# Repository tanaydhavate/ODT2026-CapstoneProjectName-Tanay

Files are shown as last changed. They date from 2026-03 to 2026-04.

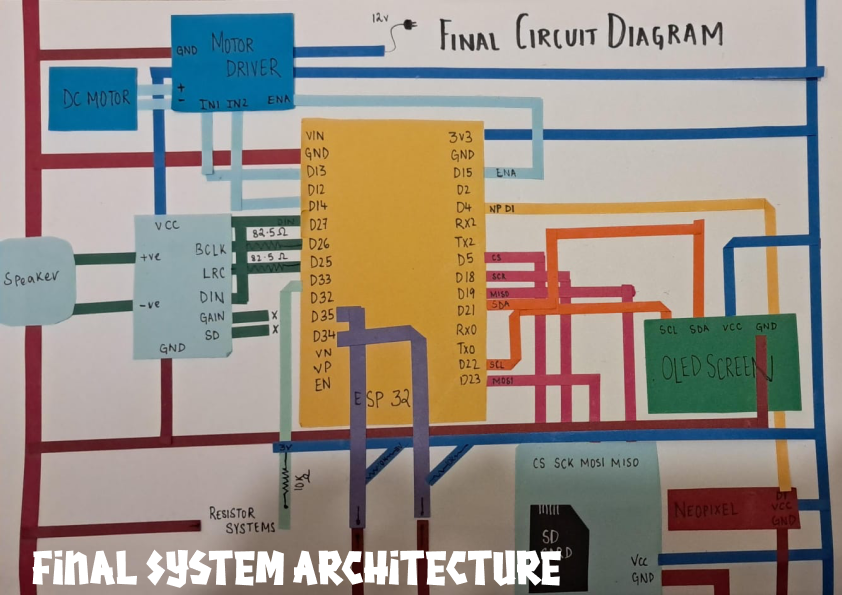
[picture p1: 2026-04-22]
Electronics Details/Circuit Diagram.png

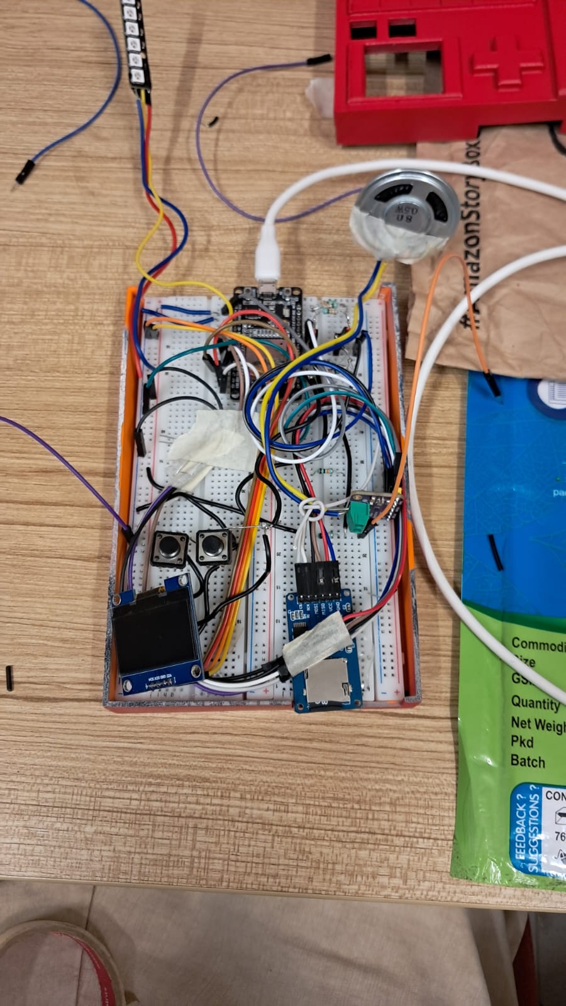
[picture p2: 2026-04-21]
Media/Week2/WhatsApp Image 2026-04-22 at 2.16.32 AM.jpeg

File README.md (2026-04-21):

**Project Title**

Gotta Code Em All

**📌 Project Overview**

[Provide a short description of your project

**📂 Repository Structure**
1. Electronics Details
2. Mechanical Details
3. Software Details
4. Project Documents
5. Media

**⚙️ How to Navigate This Repository**

Electronics Details → Circuit, components justification

Mechanical Details → Sketches, CAD, and fabrication

Software Details → Code, logic, and implementation

Project Documents → Design thinking, planning, testing

Media → Weekly progress and final output

**👥 Team Members**
Tanay Dhavate
Sachit Patnaik

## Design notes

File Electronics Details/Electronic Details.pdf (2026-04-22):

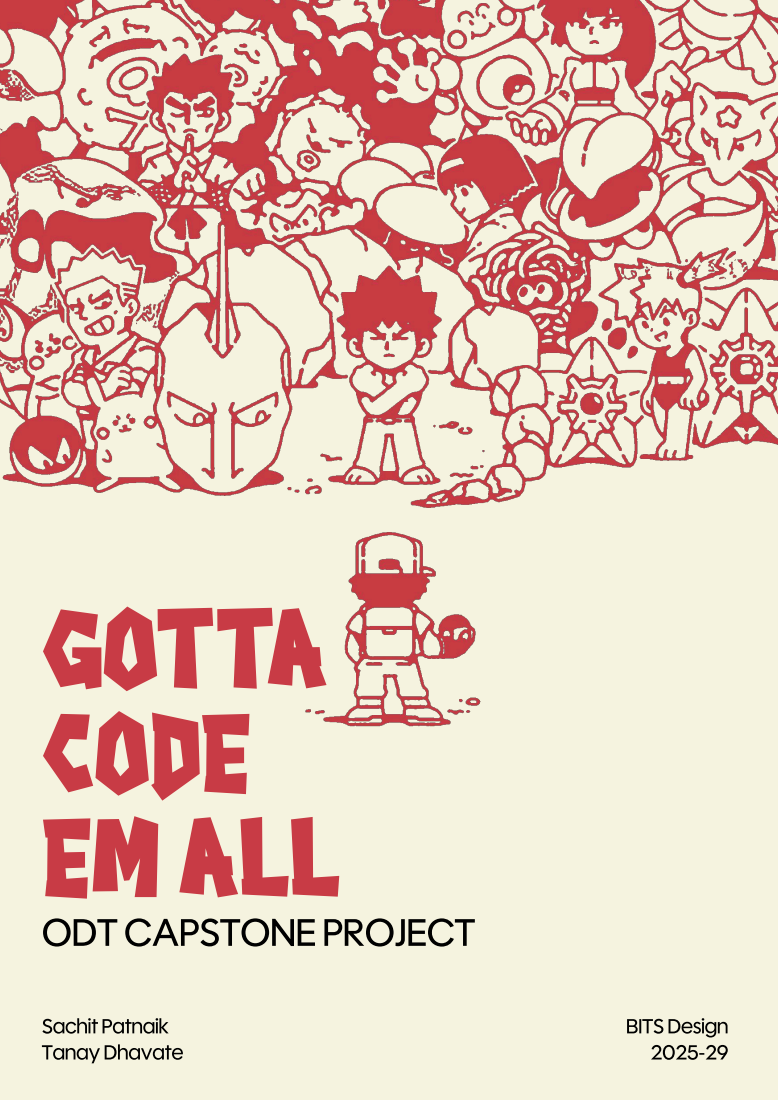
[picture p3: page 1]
gotta code em all; Sachit Patnaik Tanay Dhavate; BITS Design 2025-29

ODT CAPSTONE PROJECT

# electronics

# OLED

BIN Files

### BOOT

ON/OFF

WAV Files

## Amplifier

Animations

# ESP32

### Amplifier

Scan/Catch

ADC CIRCUIT

### SCAN

Motor

Driver

Sensor

Speaker

DC Motor

12V

SD READER | Neopixel Strip

#006

The block diagram shows an ESP32-based Pokédex where the

ESP32 controls all system functions, handling inputs from the

BOOT and SCAN buttons and identifying Pokémon through an

analog sensor. It outputs visuals to an OLED display and

Neopixel LEDs, plays audio through an I2S amplifier and speaker,

and drives a motor for haptic feedback during captures. Data

for animations and sounds is stored on a microSD card via SPI,

and the system is powered through a regulated supply,

combining multiple modules into a single interactive device.

# component table

# ESP 32

## Microcontroller

No.
1

## Purpose

Main microcontroller
that runs the entire
system (code execution,
I/O control)

## Justification

Handles I2C (OLED), SPI (SD card), I2S
(audio), ADC (sensor), and GPIO

simultaneously. Powerful enough for animations + audio playback + logic. Built in WiFi/Bluetooth (not used here, but future expandable)

## Micro SD Card 1

# 1.3in OLED Display (SH1106)

# Neopixel LED Strip(8 LEDs)

# I2S Audio

# Amplifier

## Speaker

1

1

1

1

Stores audio files and
animation frames as .bin
and .wav files

Displays Pokemon
animation sequence and
stats. Also shows text
instructions

Provide a visual que for
key events through the
process(scanning,

catching, caught/not
caught, Type)

Convert electric signals
into readable sound
waves for the speaker

Play a short description
of each Pokemon after
each scan and sound
effects for the pokeball

Esp internal flash memory would be too small to hold all the files needed. We also wanted one single place to store all the functions to be easily called upon later

Provided key visual data about pokemon. Screen is also I2C, only 2 pins needed to connect. Monochrome screen provided a good contrast and retro aesthetic

We needed a way to show bootup, catch and type animations without using the screen, chose a strip over a ring because of its smaller profile and it fit with our aesthetic

Needed to regulate sound playback and allow the speaker to work because the ESP outputs audio digitally, not analog

Wanted to go for a analog, retro aesthetic which was achieved by the speakers sound quality

# Motor Driver Module

No.
1

# Purpose

## Controls the direction and power supplied to the DC motor

# Justification

## ESP32 cannot drive motors directly due to current limitations, allows forward and reverse motion for shake effects . Protects the microcontroller from damage

# DC Motor 1

# Push Buttons

# Micro SD Card Reader

2

1

## Create the effect of a pokeball catch animation by shaking it side to side

## BOOT and SCAN buttons to activate whole system and trigger scan and catch mechanisms

## Interfaces the microSD card with the ESP32 to enable reading of stored data

## Creates haptic feedback to the user and helps complete the entire system flow. Used a DC motor over a servo due to technical setbacks while 3D printing the Pokeball model

## Simple inputs that can be read easily

by the ESP32. Clear use case for users,

## can also have dual functions with long press

## Uses SPI protocol for reliable and relatively fast communication. Allows the ESP32 to access external storage beyond its internal memory, required for streaming animation frames and audio files in real time

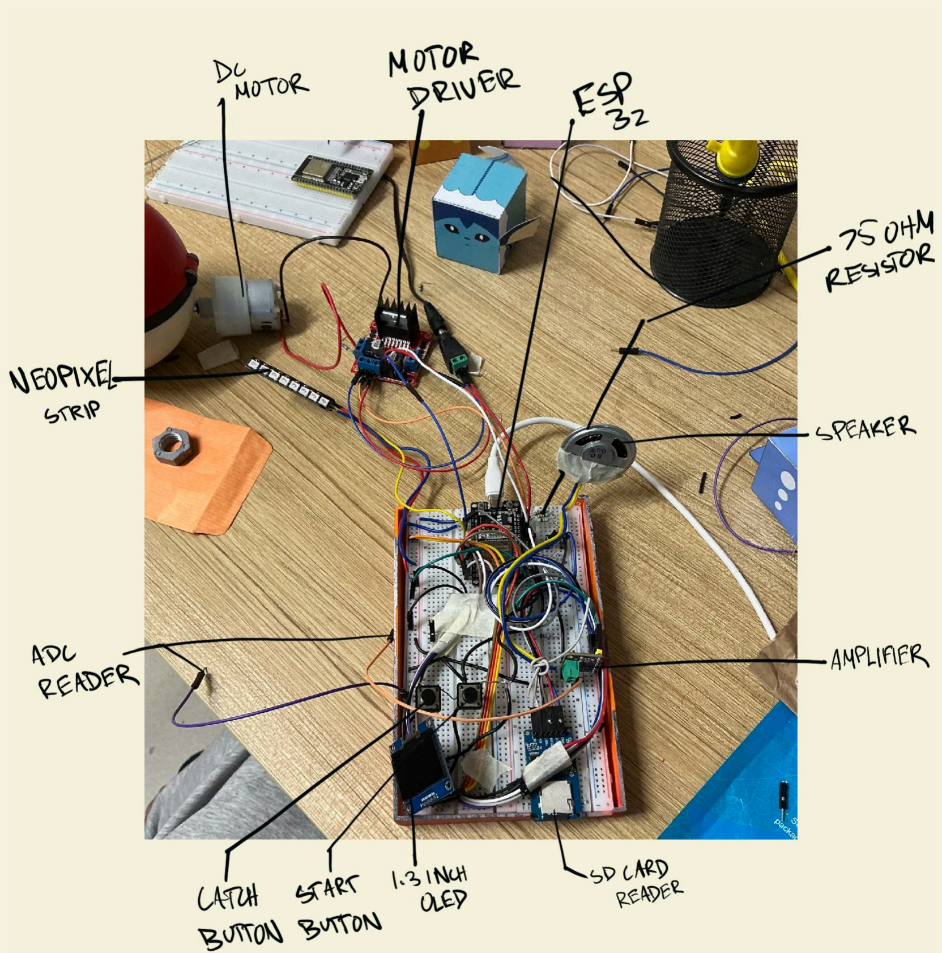
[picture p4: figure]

# Labeled circuit

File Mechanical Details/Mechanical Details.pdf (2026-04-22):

gotta code em all; Sachit Patnaik Tanay Dhavate; BITS Design 2025-29

ODT CAPSTONE PROJECT

# material choice

## Materials

Main Material 1- PLA
We chose to 3D print both the Pokedex case and Pokeball using PLA.
- Structure- We chose PLA because it would give us print with accurate dimensions which was essential due to us needing to put the breadboard and most of the electronics internally. This was preferred over MDF wood due to it taking longer to assemble and it would not be as structurally sound). The overall cases turned out to be very durable and survived many drops from height and other damage.
- Adaptability- 3D printing also allowed us to change our design as the project progressed such as changing port slot sizes, height and thickness which would have been a laborious task with other materials (MDF, acrylic, metal, cardboard. We were also able to modify the physical structure easily through sanding, filing, sawing and drilling.
- Aesthetics- The original Pokedex in the shows and toys has a matte, plastic finish which we wanted to accurately represent. We did this by further sanding the prints and spray painting

Material 2- Paper
- Used to make the models of pokemon as cubes, done with thick glossy sheets
- Simple models, allowed us to use online cutout sheets of pokemon
- Inside was hollow, giving space to insert the unique resistor set for each pokemon as part of the ADC identification system

Material 3- Sun board
- Mainly used to reinforce the pokemon models to make inserting wires easier
- Chosen due it being easy to cut while remaining durable and providing adequate structural support

# Fabrication process

2. Fabrication Steps :
A documented "Build-log" (e.g., "1. Laser cutting frame," "2. Heat-staking threaded inserts").
1. Create rough sketches of layout taking inspiration from an actual pokedex and modifying to fit the components of our project (OLED screen, push buttons, speaker, ADC reader )
2. Take dimensions of breadboard and pokemon models(made from paper cutouts) for the pokedex and DC motor dimensions for the pokeball
3. Make initial 3D models using these parameters, modified according to changes in circuitry
4. Print first models using a 3D printer and PLA material.
5. Create paper models of pokemon
6. Sanding and filing imperfections of 3d prints
7. Spray painted both models
8. Install Resistor system in each pokemon
9. Fit breadboard and wiring and some electronic components(Speaker amp, SD card reader) inside the model.
10. External electronic components(Push button, OLED, Speaker, Neopixel strip) attached to exterior of pokedex for interaction while being connected to breadboard inside
11. Connected DC motor to Pokeball and attached it to the final circuit in the pokedex
12. Secured components ran tests to ensure the whole system works

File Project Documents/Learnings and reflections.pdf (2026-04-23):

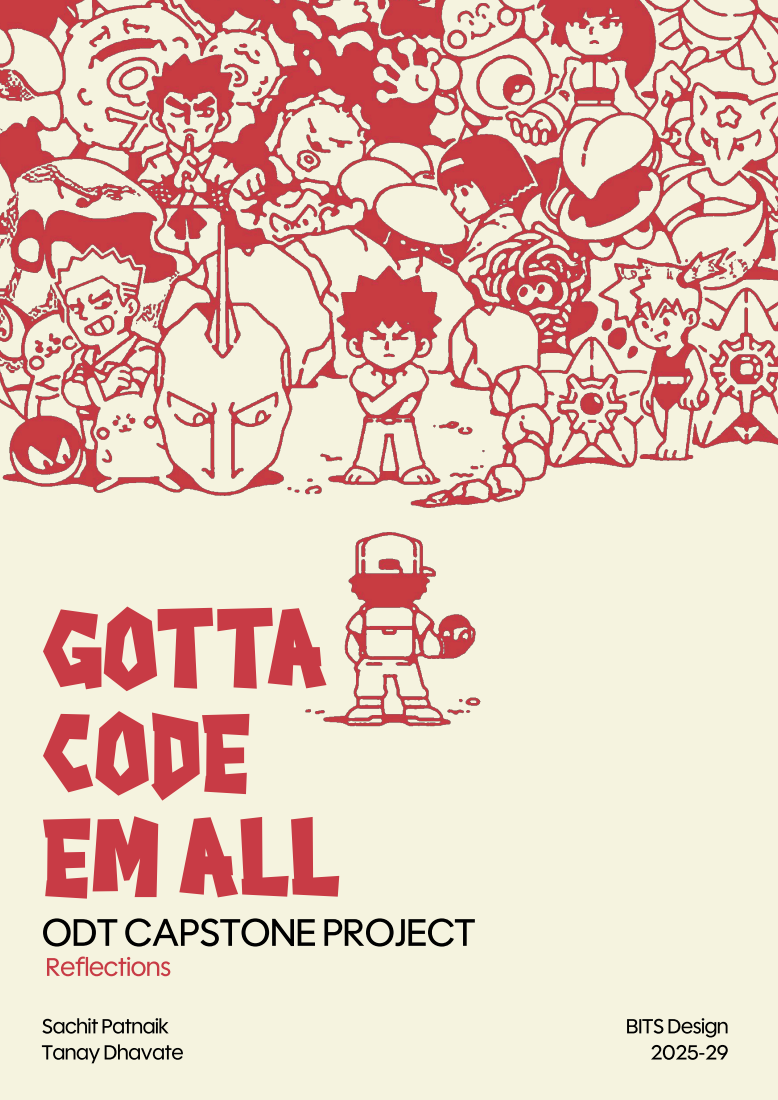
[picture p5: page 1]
gotta code em all; Sachit Patnaik Tanay Dhavate; BITS Design 2025-29

ODT CAPSTONE PROJECT
Reflections

# Team Reflection

## How did the team work together?

- The team worked well together with very few conflicts , and those that did arise were only over trivial matters like presentation style, nothing substantial - Our shared interest in Pokémon and interactive electronics meant we were naturally aligned on the direction of the project from the start - Tasks divided cleanly between hardware and software, with both members contributing across both where needed

## What worked well?

### - Shared enthusiasm for the subject made collaboration feel natural rather than forced - Decision-making was fast because we agreed on the core vision early and rarely second-guessed it - The division between physical build and software work played to each person’s strengths

## What could be improved?

### - Very little any improvements would be minor and none relate to team dynamics - Could have documented decisions and testing results more consistently throughout the process

#009

#003

#006

# Techinichal Reflection

## Key Technical Challenges

- Getting the I2S amplifier to output clean audio was the most difficult hardware problem , distortion persisted across multiple file formats and settings
- Converting GIFs into bitmap sequences and then into raw binary frame files required a custom pipeline and manual adjustment of light/dark

inversion per Pokémon
- Running out of GPIO pins forced a workaround using pins 34 and 35, which are input-only with no internal pull-up resistors

## What Did We Learn?

- Learned to work through component documentation and data sheets independently, figuring out the OLED and I2S amplifier without handholding was challenging but deeply rewarding
- Understood how non-blocking timing works in practice .replacing sleep() with ticks_diff() to allow multiple outputs to run simultaneously
- Gained hands-on experience with ADC stability, I2S audio streaming, binary frame rendering, and SD card file management on a microcontroller

## Mistakes & Debugging

- GPIO 12 on the ESP32 nearly damaged the board ,l earned to check pin boot modes before using any GPIO for peripherals
- Spent significant time debugging audio distortion before discovering the fix: a 75Ω resistor between the GPIO and the data pin of the amplifier, which resolved the issue immediately
- Multiple crash cycles taught us to always initialise peripherals sequentially with deliberate delays rather than all at once

#137

# Design Reflection

## Did the experience match your intention?

- Largely yes ,the core fantasy of scanning a figure and catching a Pokémon came through clearly and users responded strongly to it
- The physical Pokéball shaking was the standout moment and landed exactly as intended

## What Would You Improve?

- The placement and integration of the Pokéball into the overall form needs more refinement, it currently feels like an accessory rather than a natural part of the device
- With more time and another iteration of prints, the enclosure and physical layout would be significantly more considered
- The product would benefit from being treated as a fully resolved object , cleaner wiring, a

custom PCB, and a more refined finish

## User Feedback Insights

- Users found the interaction intuitive and engaging , most completed it unaided
- Repeat interactions were common, driven by the variety of Pokémon and the rarity system
- Jury feedback highlighted that more user research and ergonomic consideration would strengthen the design , particularly around how the user holds the device while also interacting
with the Pokéball
- More rounds of user testing would inform better decisions around button placement, screen legibility at different angles, and the physical form of the figures

#130

# Tanay’s Reflection

## What I Learned

How to connect basic and complex circuitry and manage hardware in set dimensions(the pokedex)

How to troubleshoot issues, both hardware and software. I found that our errors were rarely on the software side but rather a issue with our connections. This taught me not to jump to complex solutions but to first check at the basic level

integrating multiple components, testing and comparing component hypothesizes and managing varying current needs for different components while keeping the circuit efficient and streamlined

## What Didn’t Work

Getting something on the first try rarely ever worked, especially the more complex and integrated our systems became
Trying to optimize our hardware and 3D prints was a struggle at the start and we had to change some of our ideas and execution because of these limitations

## What I Am Proud Of

I’m most proud of how we set out a goal at the start, and although we didn’t end up with what we intended(camera sensor),

the end result was something that I am very satisfied with . Getting the entire system to run after weeks of work felt

### satisfying

The skills I learnt are something I hope I won’t forget and can use further in my work
We also did not fry anything during the final project which surprised me honestly

#306

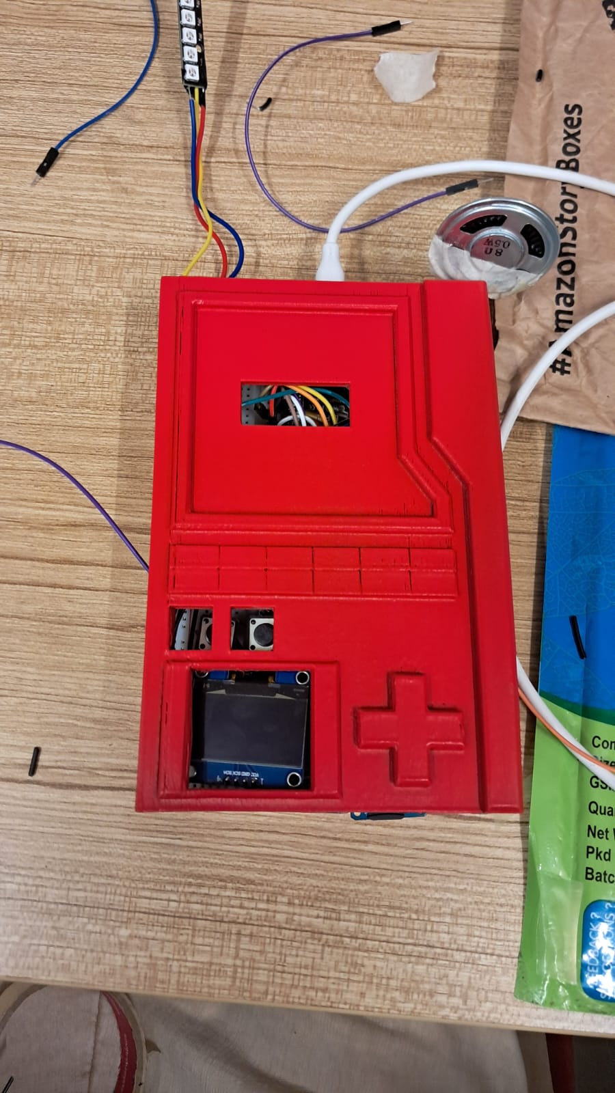
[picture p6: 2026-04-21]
Media/Week2/WhatsApp Image 2026-04-22 at 2.16.31 AM.jpeg

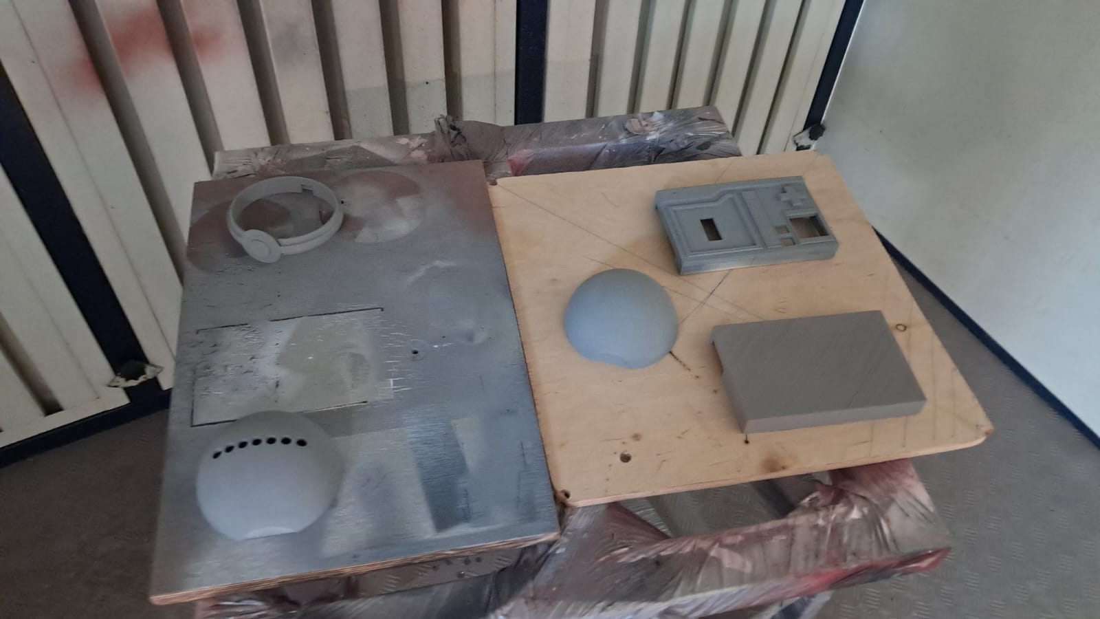
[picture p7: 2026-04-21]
Media/Week1/WhatsApp Image 2026-04-22 at 2.16.39 AM.jpeg

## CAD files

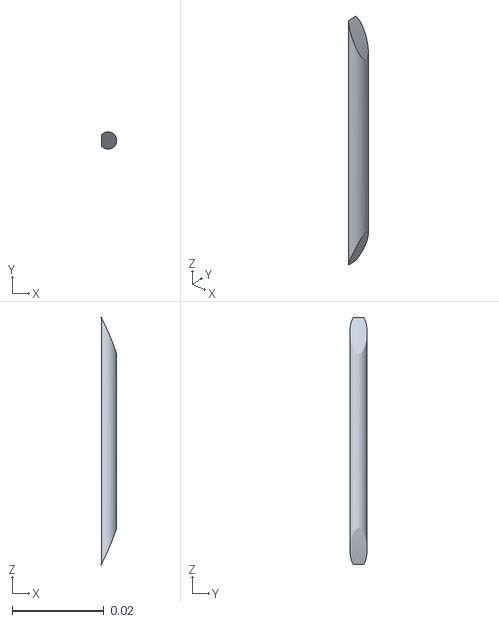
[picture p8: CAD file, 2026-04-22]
Mechanical Details/3D STL files/pin.stl
0.00338 x 0.00375 x 0.0539

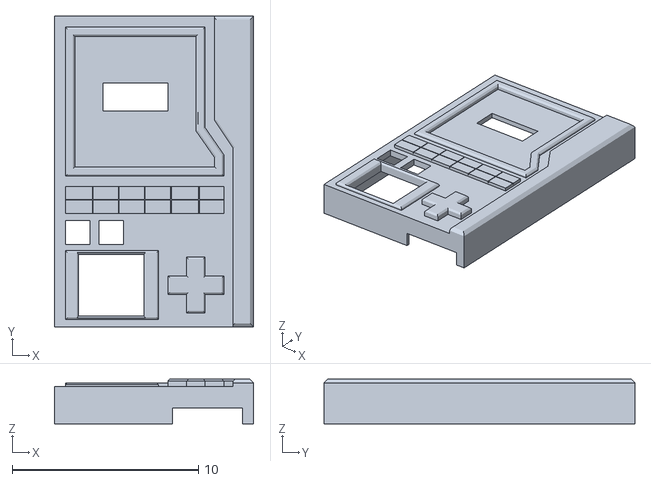
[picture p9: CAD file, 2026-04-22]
Mechanical Details/3D STL files/pokedex top.stl
10.7 x 16.7 x 2.40

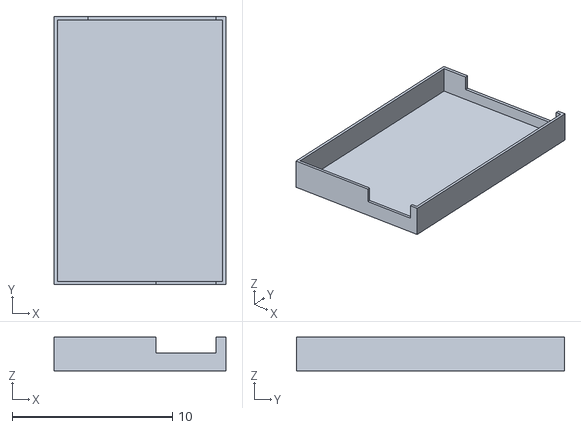
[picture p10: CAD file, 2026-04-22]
Mechanical Details/3D STL files/dex bottom.stl
10.7 x 16.7 x 2.10

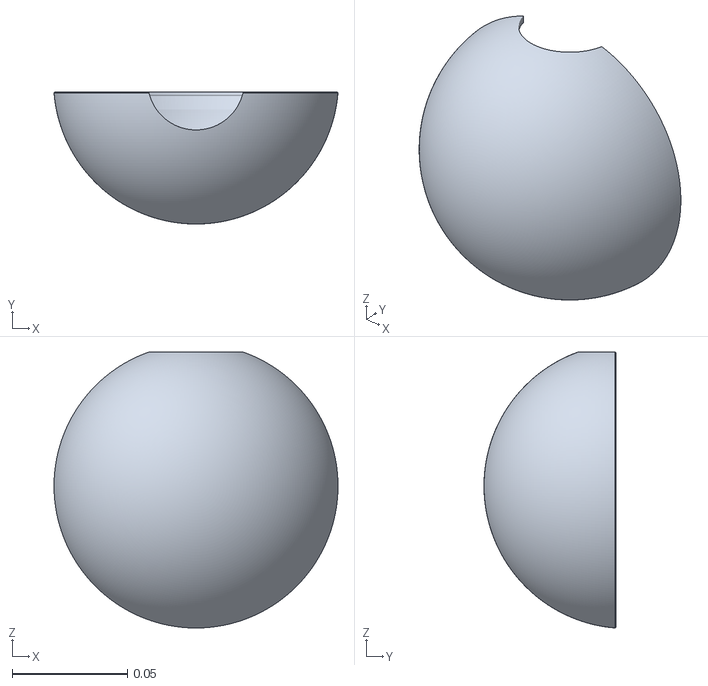
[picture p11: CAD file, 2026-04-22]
Mechanical Details/3D STL files/shell 1.stl
0.123 x 0.0574 x 0.12

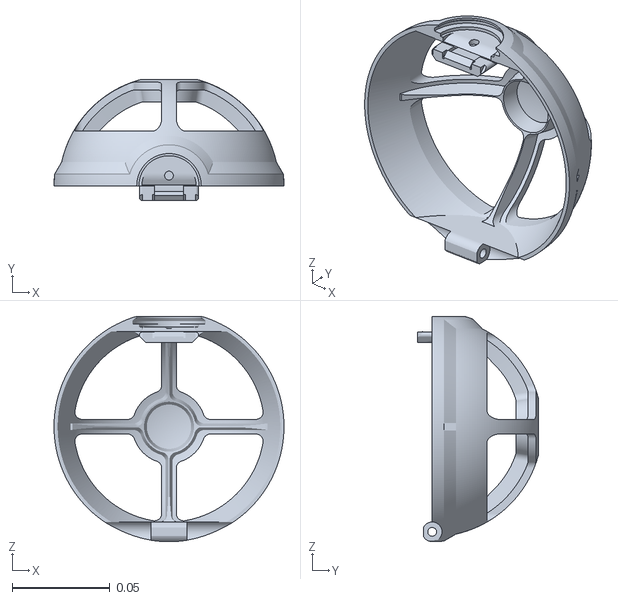
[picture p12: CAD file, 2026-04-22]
Mechanical Details/3D STL files/inner shell 2.stl
0.118 x 0.0619 x 0.115

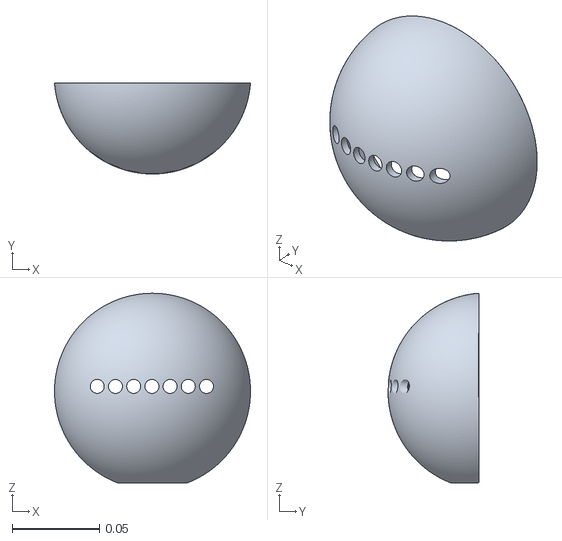
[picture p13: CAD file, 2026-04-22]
Mechanical Details/3D STL files/BOTTOM.stl
0.112 x 0.052 x 0.108

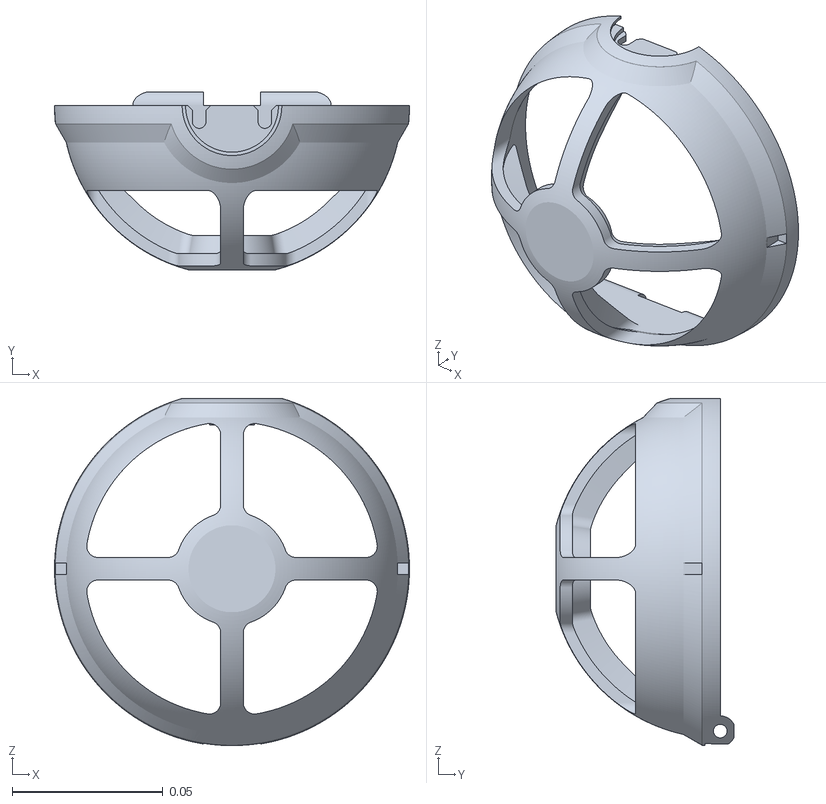
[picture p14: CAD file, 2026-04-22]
Mechanical Details/3D STL files/inner shell 1.stl
0.118 x 0.0589 x 0.115

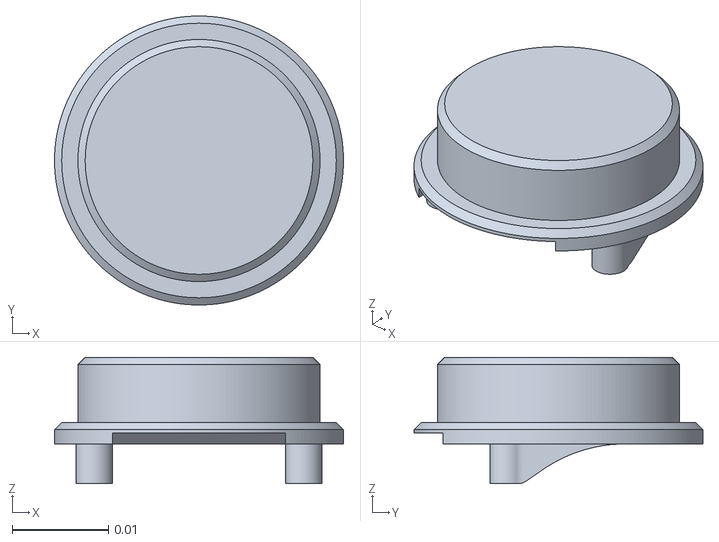
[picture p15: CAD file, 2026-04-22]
Mechanical Details/3D STL files/button inner.stl
0.03 x 0.03 x 0.0131

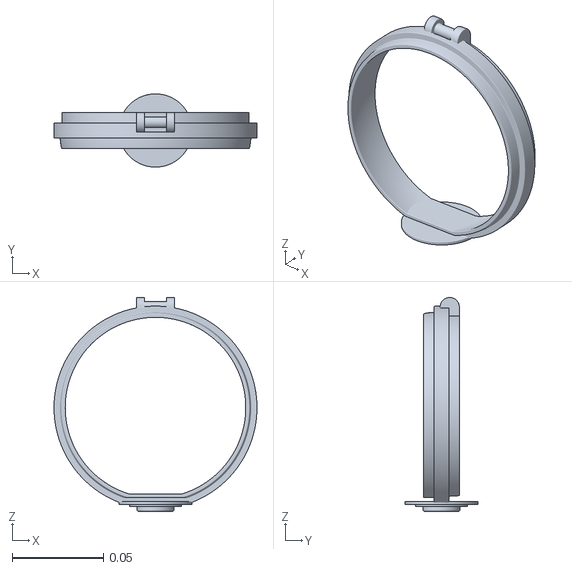
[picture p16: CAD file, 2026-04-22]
Mechanical Details/3D STL files/mid.stl
0.111 x 0.04 x 0.117

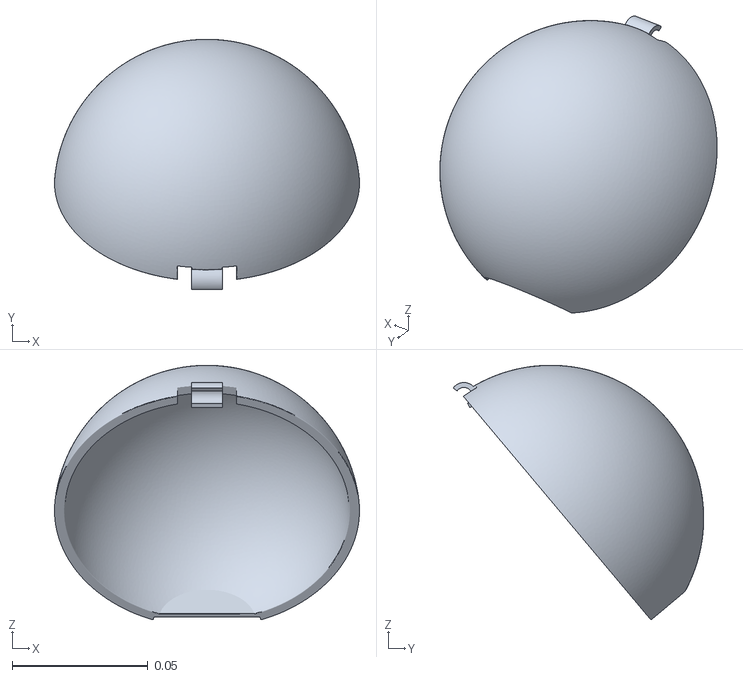
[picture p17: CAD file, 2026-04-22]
Mechanical Details/3D STL files/top.stl
0.112 x 0.0921 x 0.0935

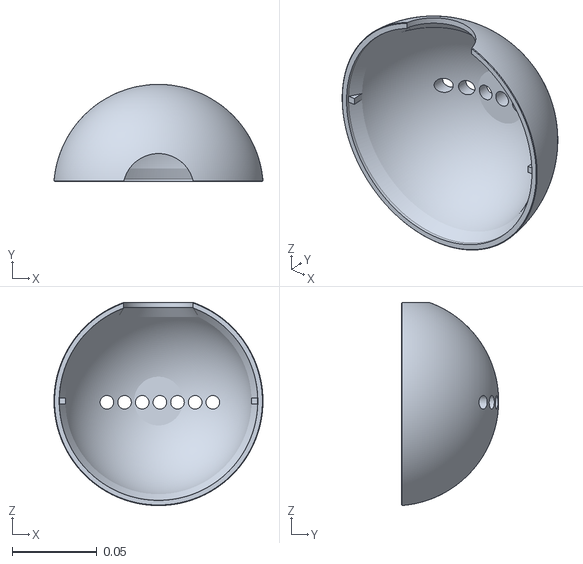
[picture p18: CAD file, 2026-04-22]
Mechanical Details/3D STL files/ shell 2.stl
0.123 x 0.0573 x 0.12

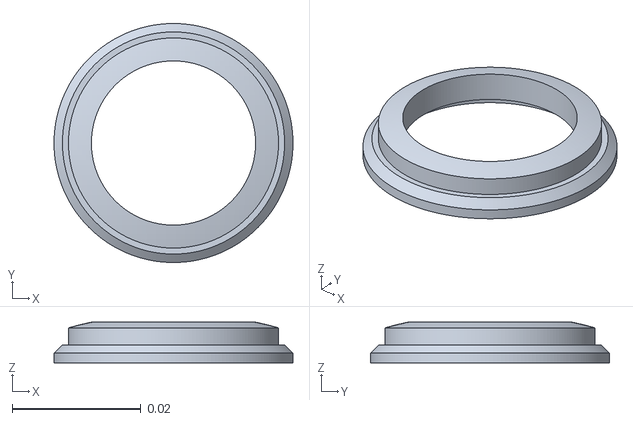
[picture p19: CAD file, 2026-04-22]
Mechanical Details/3D STL files/button outer.stl
0.0371 x 0.0371 x 0.00633

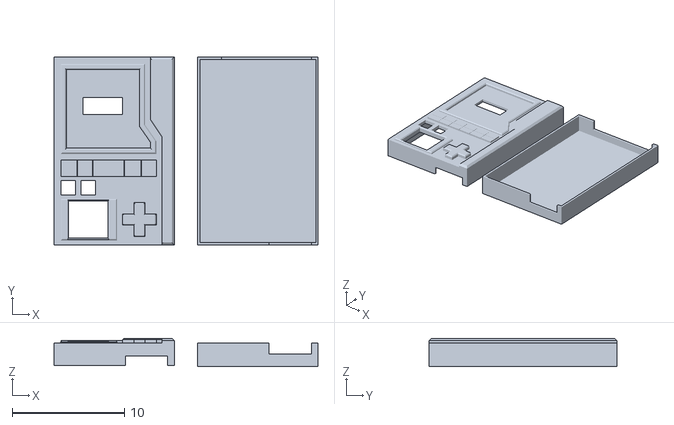
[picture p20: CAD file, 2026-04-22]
Mechanical Details/3D STL files/pokedex bottom.stl
23.5 x 16.7 x 2.50

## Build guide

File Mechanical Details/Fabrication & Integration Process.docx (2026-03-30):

# Fabrication and Integration Process

### 1. Material Choice Justification :

Why choose Acrylic over MDF? Why PLA instead of Resin? (e.g., weight, durability, aesthetic)

2. Fabrication Steps :

A documented "Build-log" (e.g., "1. Laser cutting frame," "2. Heat-staking threaded inserts").

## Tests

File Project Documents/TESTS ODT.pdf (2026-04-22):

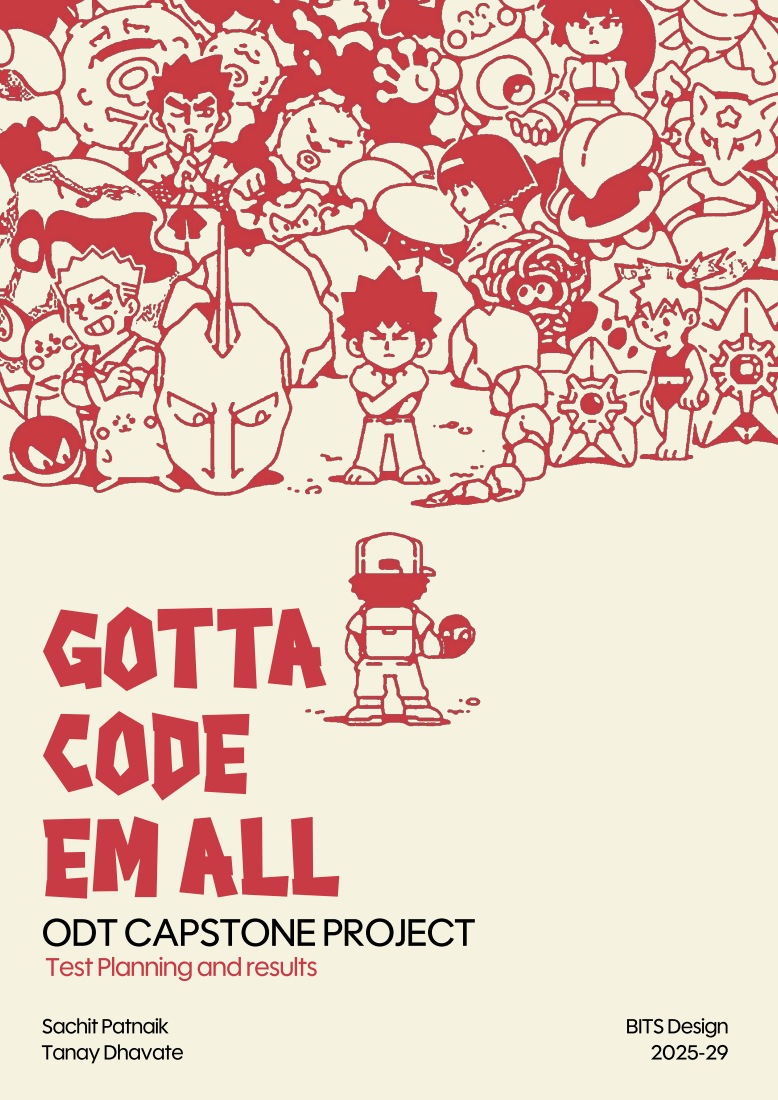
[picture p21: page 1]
gotta code em all; Sachit Patnaik; Tanay Dhavate; BITS Design 2025-29

ODT CAPSTONE PROJECT

Test Planning and results

# ADC Feasibility

# tests conducted

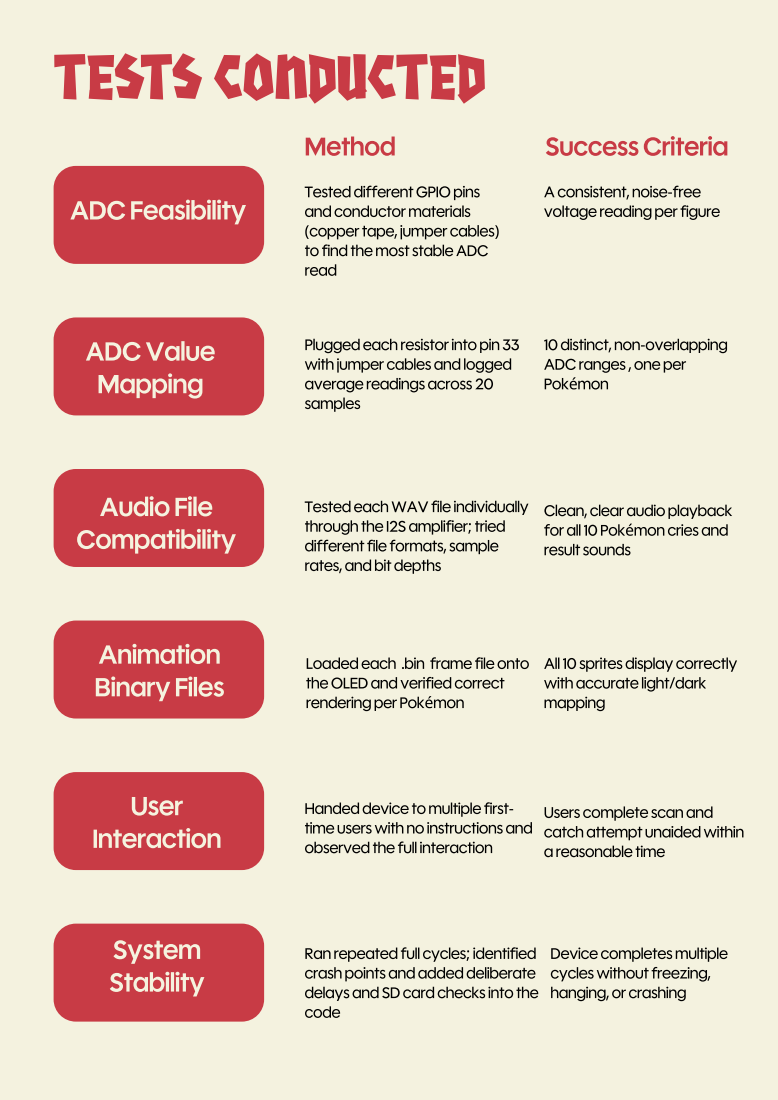
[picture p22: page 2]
Method; Success Criteria; ADC Value; Mapping; Audio File; Compatibility; Animation; Binary Files; User; Interaction; System; Stability

Tested different GPIO pins
and conductor materials
(copper tape, jumper cables)
to find the most stable ADC
read

A consistent, noise-free
voltage reading per figure

Plugged each resistor into pin 33
with jumper cables and logged
average readings across 20
samples

10 distinct, non-overlapping
ADC ranges , one per
Pokémon

Tested each WAV file individually
through the I2S amplifier; tried
different file formats, sample
rates, and bit depths

Clean, clear audio playback
for all 10 Pokémon cries and
result sounds

Loaded each .bin frame file onto
the OLED and verified correct
rendering per Pokémon

All 10 sprites display correctly
with accurate light/dark
mapping

Handed device to multiple first-
time users with no instructions and
observed the full interaction

Users complete scan and
catch attempt unaided within
a reasonable time

Ran repeated full cycles; identified
crash points and added deliberate
delays and SD card checks into the
code

Device completes multiple
cycles without freezing,
hanging, or crashing

# ADC Feasibility

# tests conducted

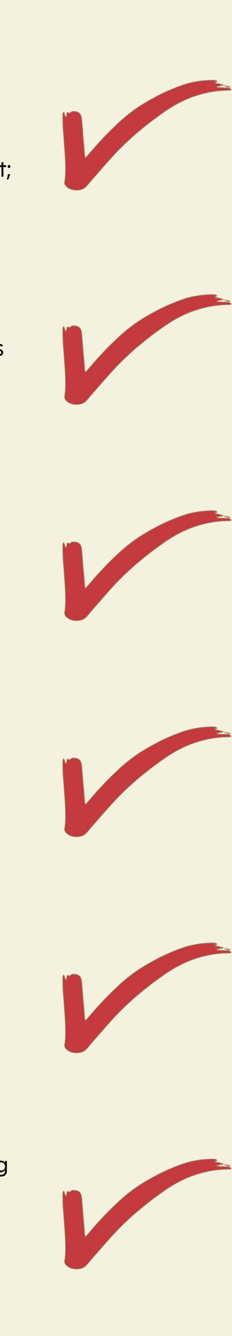
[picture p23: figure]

GPIO 33 with jumper cables gave the most stable reads; copper tape was inconsistent; GPIO 12 nearly damaged the ESP32

# Outcome

# ADC Value Mapping

10 distinct ranges confirmed with generous spacing between each value

# Audio File

# Compatibility

Distorted audio resolved by adding a 75Ω resistor between GPIO and amp data pin; clean playback achieved across all files

# Animation Binary Files

All 10 sprites render correctly; light/dark inversion manually adjusted per Pokémon

# User Interaction

All users successfully completed the full interaction unaided; many returned for repeat attempts

# System Stability

Crashes resolved by redoing wiring, adding boot delays, and inserting SD card initialisation checks

# Observations

## User Behaviour

### - Users instinctively picked up the figures and attempted to plug

### them in without instruction

### - The 5-second hold confused some users initially but the OLED

### countdown made it clear quickly

### - Multiple users returned to try different figures : the variety of

### Pokémon and rarity system drove repeat engagement

### - The physical Pokéball shaking created a strong reaction and was

### consistently the most memorable moment

## Pain Points

### - First-time users occasionally released the SCAN button too early

### before understanding the full 5-second hold

### - Some users were unsure whether the device had registered their

### plug-in before the animation started

### - The boot sequence was occasionally mistaken for a malfunction

### during the LED fade-off

#130

# Improvements required after user test

# - Add a short visual or audio cue immediately on plug-in to confirm

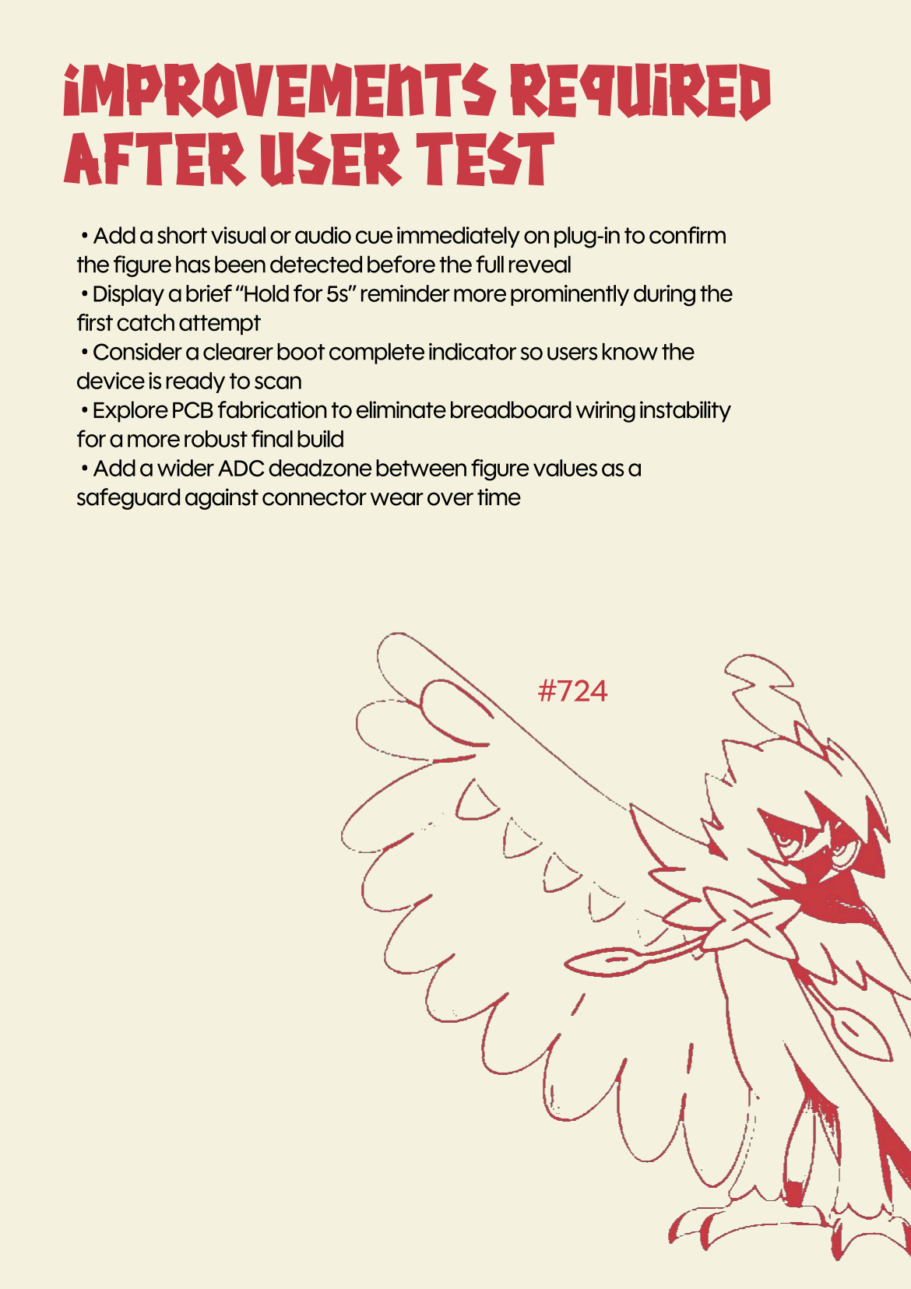
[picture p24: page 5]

the figure has been detected before the full reveal - Display a brief “Hold for 5s” reminder more prominently during the first catch attempt - Consider a clearer boot complete indicator so users know the device is ready to scan - Explore PCB fabrication to eliminate breadboard wiring instability for a more robust final build - Add a wider ADC deadzone between figure values as a safeguard against connector wear over time

#724

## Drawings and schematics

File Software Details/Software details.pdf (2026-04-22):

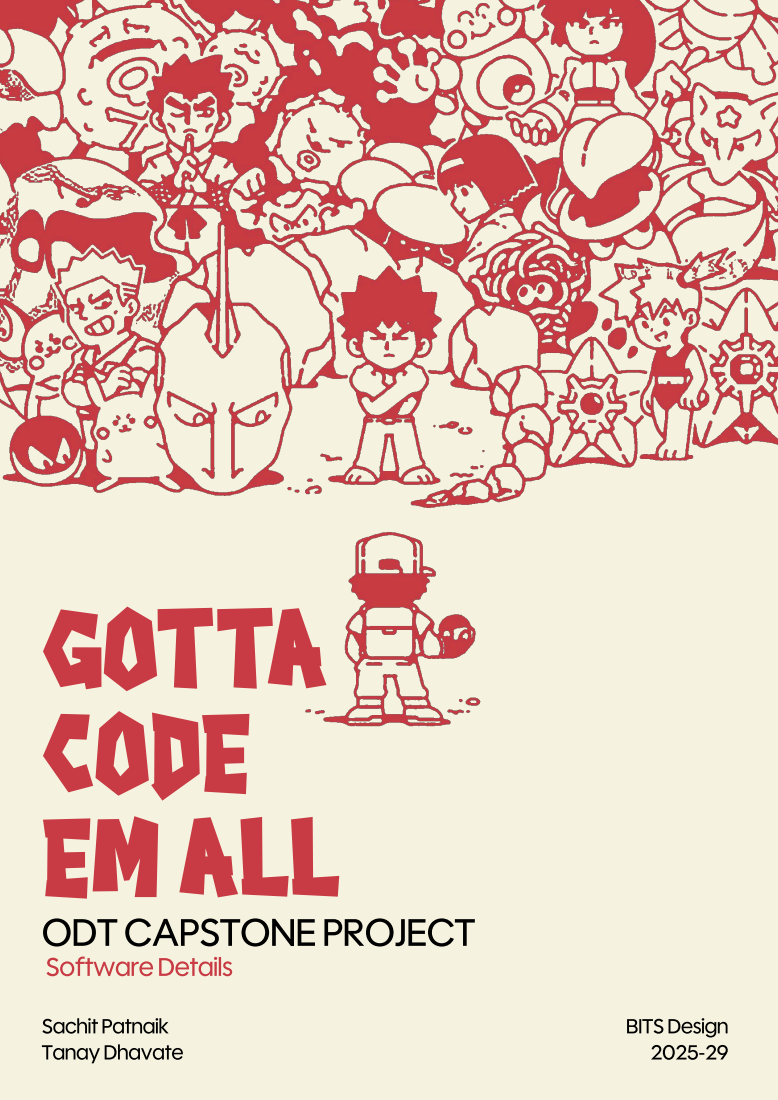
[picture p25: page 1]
gotta code em all; Sachit Patnaik Tanay Dhavate; BITS Design 2025-29

ODT CAPSTONE PROJECT
Software Details

# Software map

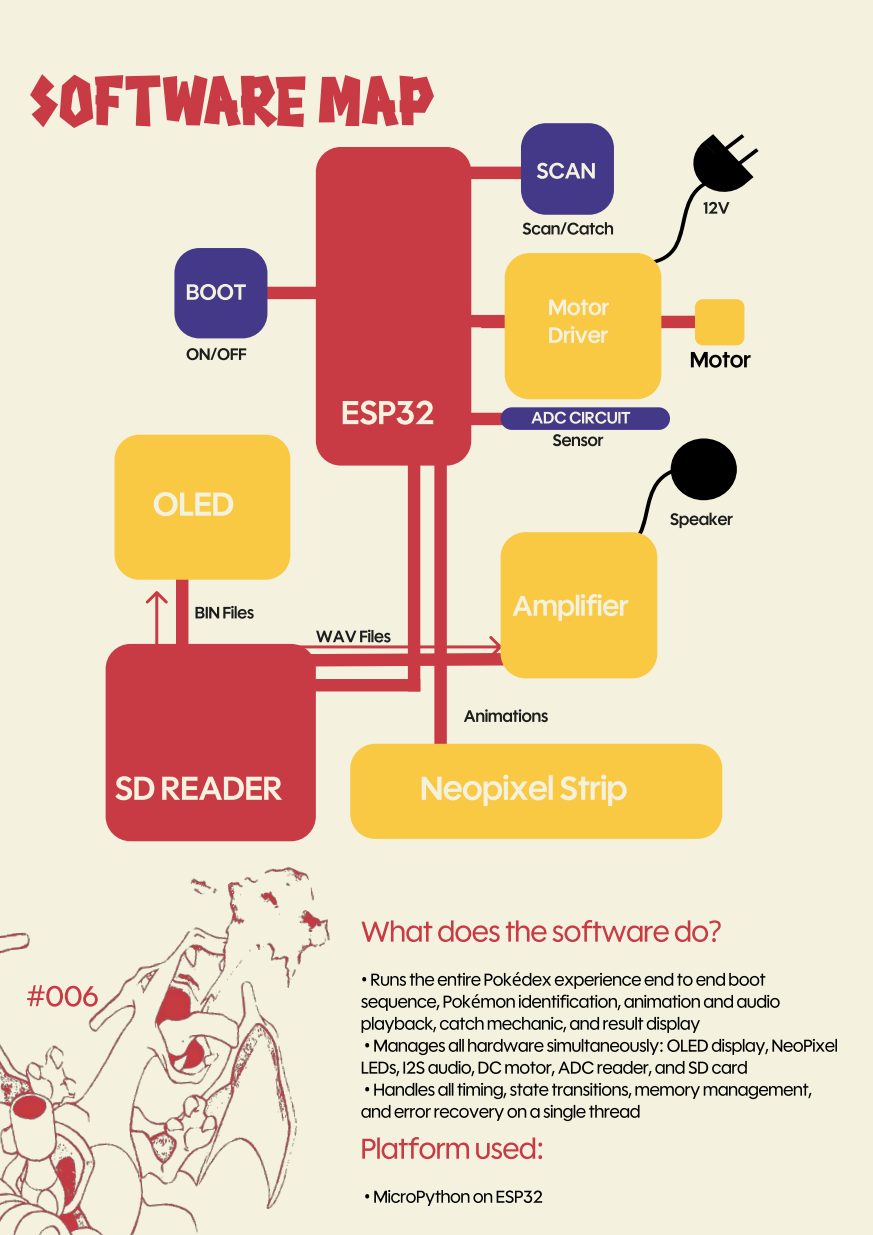
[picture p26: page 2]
OLED; BIN Files; BOOT; ON/OFF; WAV Files; Amplifier; Animations; ESP32; Scan/Catch; ADC CIRCUIT; SCAN; Motor; Driver; Sensor; Speaker; SD READER; Neopixel Strip; • MicroPython on ESP32

What does the software do?

• Runs the entire Pokédex experience end to end boot

sequence, Pokémon identification, animation and audio

playback, catch mechanic, and result display

• Manages all hardware simultaneously: OLED display, NeoPixel

LEDs, I2S audio, DC motor, ADC reader, and SD card

• Handles all timing, state transitions, memory management,

and error recovery on a single thread
Platform used:

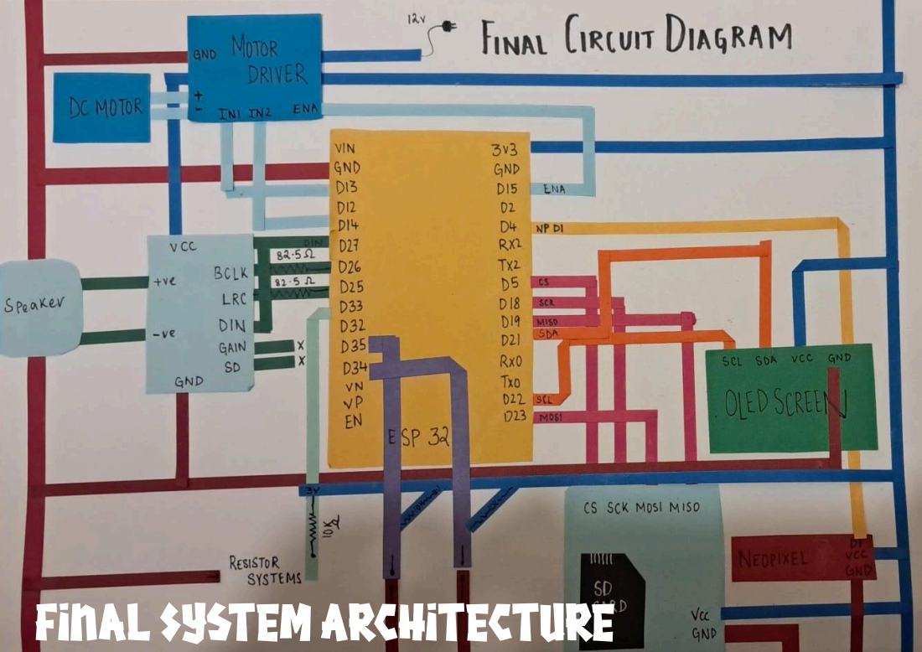
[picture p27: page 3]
Final layout

concept art FINAL

Final System Architecture

# system logic

1. User presses BOOT button
2. ESP32 initialises every peripheral one by one SD card, LEDs, OLED, audio, ADC, buttons, motor
3. Boot animation plays on LEDs and OLED; device reaches ready state
4. User plugs in a Pokémon figure and presses SCAN
5. ESP32 reads the ADC pin 20 times and averages the voltage
6. Averaged value is matched to a Pokémon from the identification table
7. Animation frames and WAV audio file are loaded from the SD card
8. Audio streams via I2S; OLED advances one animation frame every 6 audio chunks, keeping them in sync
9. NeoPixels light up in the Pokémon’s theme colour
10. Catch screen appears, user holds SCAN for 5 seconds
11. LEDs fill as a progress bar; countdown ticks on OLED
12. Catch outcome is decided silently using a random roll weighted by rarity
13. DC motor fires three times at set intervals, physically shaking the Pokéball
14. 5 seconds complete, caught or escaped sound plays
15. LEDs flood green or red; OLED displays the result with Pokémon sprite
16. Memory is cleared, state resets, device loops back to ready screen

#137

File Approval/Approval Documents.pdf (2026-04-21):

gotta code em all; Sachit Patnaik Tanay Dhavate; BITS Design 2025-29

ODT CAPSTONE PROJECT

# concept

A Pokédex is a fictional electronic device from the Pokémon anime, games, and wider franchise that serves as a digital encyclopaedia for Pokémon trainers. It is used to identify and record information about different Pokémon encountered in the world, providing details such as a Pokémon’s name, type, physical characteristics, and a short descriptive entry unique to each creature. Phe Pokédex represents the spirit of exploration and discovery that sits at the heart of the Pokémon universe, making it a, in our minds a compelling inspiration for a project that brings together identification, data display, and physical interaction.

Our original idea for the project was to build a smart Pokédex using an ESP32-CAM. The plan was for the camera to capture an image of a Pokémon, connect to Google search or image recognition tools, identify the word or name that appeared most often, and use that to determine which Pokémon had been scanned. Once identified, the system would find the corresponding Pokédex number and use the PokéAPI to fetch data such as the Pokémon’s name, type, stats, and Pokédex entry, which would then be displayed on the device. Although this concept was exciting because it used live image recognition and online data retrieval, we felt that it relied too heavily on external APIs and automation rather than reflecting the kind of hands-on input-output logic and physical interaction we had been learning in ODT.

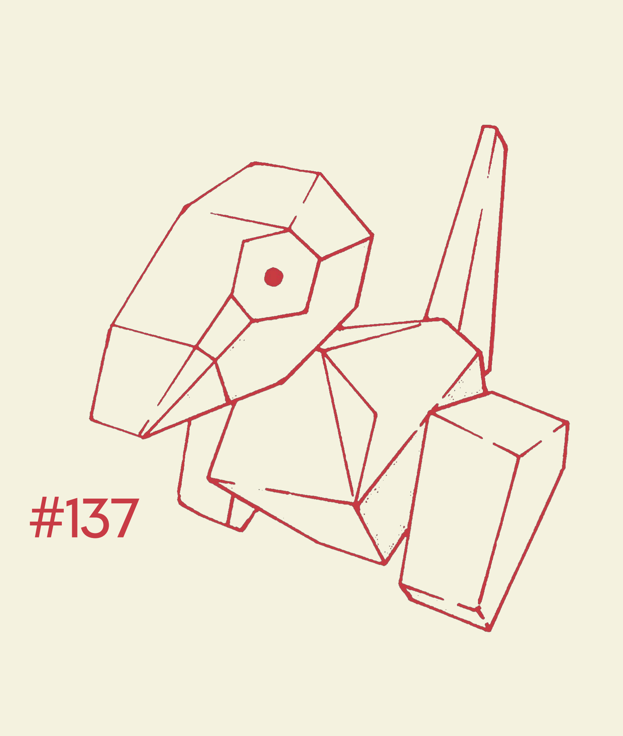
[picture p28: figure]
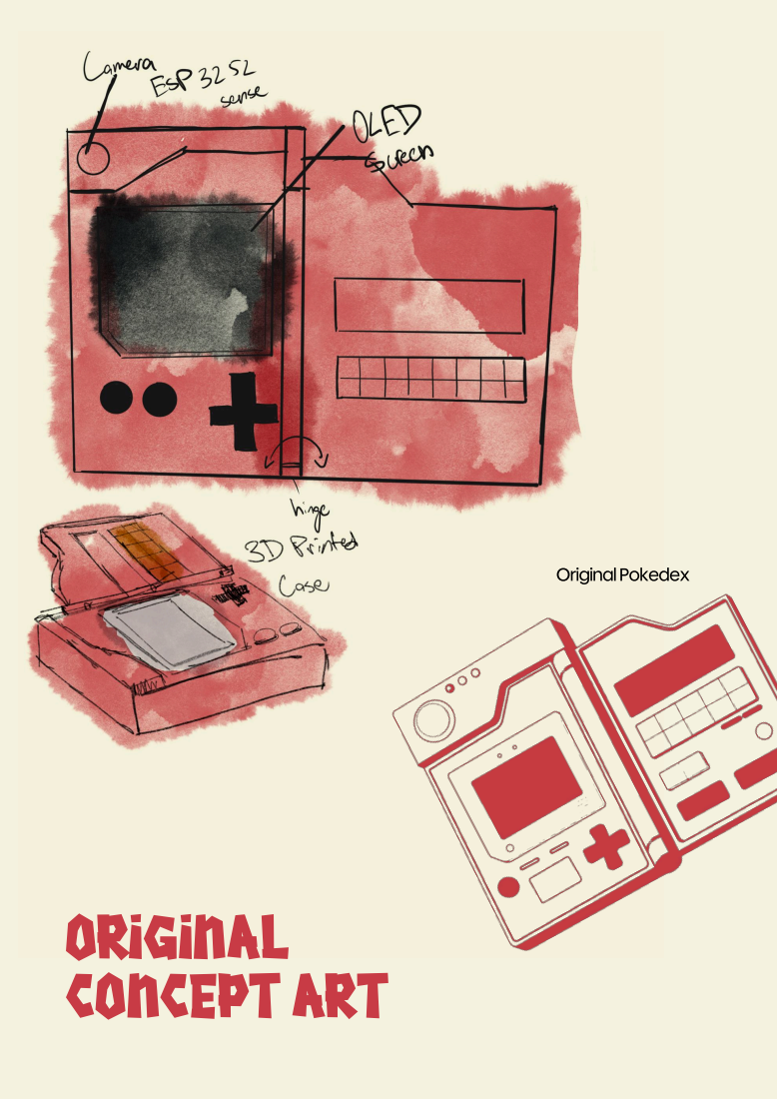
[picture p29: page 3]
Original Pokedex; original concept art

Our final design reimagined the Pokédex as a self-contained physical system rooted in embedded electronics and tangible interaction. Rather than relying on image recognition, we created a set of Pokémon figures using paper cutouts and foldable forms, each with a unique resistor embedded inside. These resistance values are read through an ADC circuit, where the measured ADC value allows the system to identify which Pokémon is connected to the scan platform, the figures plug in via a male jack into a female jack, creating a secure and repeatable connection. When the power button is pressed, the system initiates a boot sequence in which the NeoPixels light up in series while the OLED display plays a startup animation and shows “POKÉDEX.” The user then places a Pokémon figure on the platform, plugs it in, and presses the scan button, prompting the system to read the ADC value and call the corresponding Pokémon function. The NeoPixel lights up in the colour associated with that Pokémon’s type, the OLED displays its name, type, and stats, and a pre-recorded audio clip reads out its Pokédex entry aloud. Once a
Pokémon has been scanned and registered, the Pokéball becomes active. Each Pokémon has a hardcoded catch rate, and triggering the Pokéball runs a random function against this value to determine the outcome. A shaking animation simulates the catch sequence, and a light indicator, along with the OLED display, reveals whether the Pokémon was successfully caught or managed to escape. The system can be reset at any time by long-pressing the power button. This version of the project stayed true to the spirit of what we had learned, prioritising physical making, coded logic, and a layered interactive experience built from the ground up.

#130

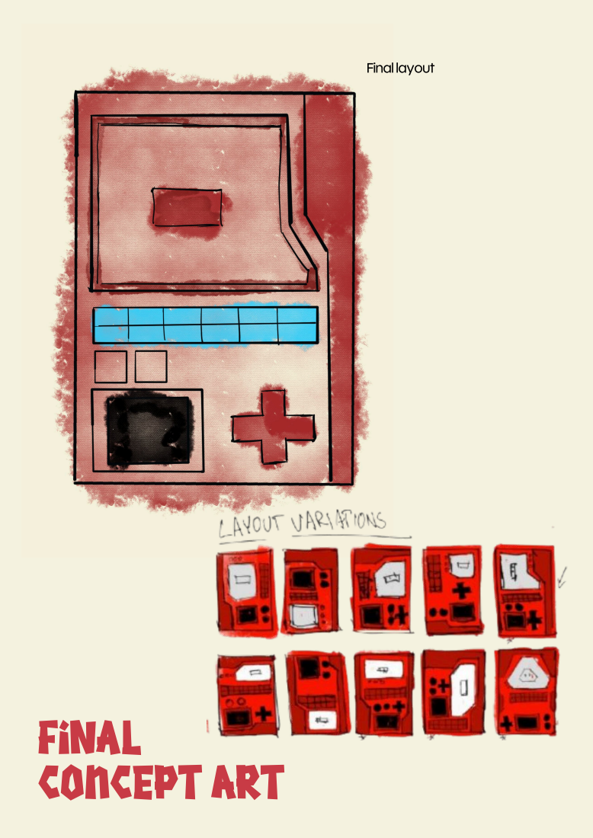
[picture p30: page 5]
Final layout; FINAL concept art

# why we chose this

We chose to work on this because we wanted to build something that was genuinely code intensive at its core , where the complexity lives in the logic of identification and sorting rather than in physical mechanics. Our first ODT summative touched on a similar idea but used capacitive touch as a fairly rough input method, so this felt like a natural opportunity to develop a more refined and considered version of that concept. We also made a deliberate choice to move away from large moving elements, motors are finicky to work with, and more importantly, most of our peers were already heading in that direction. As longtime
Pokémon fans, the theme chose itself, it gave the project a strong conceptual identity while letting us build something technically ambitious and personally meaningful.

#306

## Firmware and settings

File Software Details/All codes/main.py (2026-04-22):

from time import sleep_ms
from machine import Pin, SPI, I2C, I2S
import os, sdcard, framebuf
from SH1106 import SH1106_I2C

cs = Pin(5, Pin.OUT)
cs.value(1)
sleep_ms(1000)
spi = SPI(1, baudrate=100000, polarity=0, phase=0,
          sck=Pin(18), mosi=Pin(23), miso=Pin(19))
sleep_ms(500)
sd = sdcard.SDCard(spi, cs)
os.mount(sd, "/sd")
print("SD OK")

frames = []
with open("/sd/gengar.bin", "rb") as f:
    while True:
        data = f.read(1024)
        if len(data) < 1024: break
        frames.append(bytearray(data))
print("Frames:", len(frames))

i2c = I2C(0, scl=Pin(22), sda=Pin(21))
oled = SH1106_I2C(128, 64, i2c, addr=0x3C)
oled.fill(0)
oled.invert(True)
oled.show()

audio = I2S(0, sck=Pin(26), ws=Pin(25), sd=Pin(27),
            mode=I2S.TX, bits=16, format=I2S.MONO,
            rate=8000, ibuf=20000)

mono_buf = bytearray(1024)

def draw_info():
    oled.text("Gengar",    78,  0, 0)
    oled.text("----------",70,  9, 0)
    oled.text("Ghost",     78, 18, 0)
    oled.text("Poison",    78, 27, 0)
    oled.text("----------",70, 36, 0)
    oled.text("Kanto",     78, 45, 0)
    oled.text("1.5m 41kg", 70, 55, 0)

print("Playing...")
frame_i = 0
wav = open("/sd/gengar.wav", "rb")
wav.seek(44)

while True:
    num = wav.readinto(mono_buf)
    if num == 0: break
    if num < 1024:
        for i in range(num, 1024): mono_buf[i] = 0
    audio.write(mono_buf)
    fb = framebuf.FrameBuffer(
        frames[frame_i % len(frames)], 128, 64, framebuf.MONO_HLSB)
    oled.fill(1)
    oled.blit(fb, 0, 0)
    draw_info()
    oled.show()
    frame_i += 1

wav.close()
audio.deinit()
print("Done!")

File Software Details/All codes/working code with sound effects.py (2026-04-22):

import gc
import os
import sdcard
import framebuf
import urandom

from time import sleep_ms, sleep, ticks_ms, ticks_diff
from machine import Pin, SPI, I2C, I2S, ADC, reset
from neopixel import NeoPixel
from SH1106 import SH1106_I2C

gc.collect()

# ─── Pin Constants ─────────────────────────────────────────────────────────────
SD_CS_PIN    = 5
SD_SCK_PIN   = 18
SD_MOSI_PIN  = 23
SD_MISO_PIN  = 19

NEOPIXEL_PIN = 4
NUM_LEDS     = 16

OLED_SCL_PIN = 22
OLED_SDA_PIN = 21
OLED_ADDR    = 0x3C
OLED_W       = 128
OLED_H       = 64

I2S_SCK_PIN  = 26
I2S_WS_PIN   = 25
I2S_SD_PIN   = 27

ADC_PIN      = 33
BOOT_BTN_PIN = 34
SCAN_BTN_PIN = 35

# ─── Timing / Audio Constants ──────────────────────────────────────────────────
FRAME_WIDTH    = 128
FRAME_HEIGHT   = 64
FRAME_SIZE     = 1024
AUDIO_RATE     = 8000
AUDIO_BUF_SIZE = 8192
MONO_BUF_SIZE  = 512
LONG_PRESS_MS  = 2000
CATCH_PRESS_MS = 5000
ADC_SAMPLES    = 20

# ─── Rarity Table ──────────────────────────────────────────────────────────────
# catch_chance: numerator out of 20
RARITY = {
    "jigglypuff": ("Common",     15),
    "spheal":     ("Common",     15),
    "pikachu":    ("Common",     15),
    "mudkip":     ("Uncommon",   10),
    "snivy":      ("Uncommon",   10),
    "umbreon":    ("Rare",        2),
    "raichu":     ("Rare",        2),
    "vaporeon":   ("Rare",        2),
    "gengar":     ("Rare",        2),
    "mew":        ("Ultra Rare",  1),
}


# ══════════════════════════════════════════════════════════════════════════════
# HARDWARE INIT
# ══════════════════════════════════════════════════════════════════════════════

def init_sd():
    cs = Pin(SD_CS_PIN, Pin.OUT)
    cs.value(1)
    sleep_ms(300)
    spi = SPI(1, baudrate=100000, polarity=0, phase=0,
              sck=Pin(SD_SCK_PIN), mosi=Pin(SD_MOSI_PIN), miso=Pin(SD_MISO_PIN))
    sleep_ms(200)
    sd = sdcard.SDCard(spi, cs)
    os.mount(sd, "/sd")
    print("SD OK")
    return spi, sd

def init_neopixel():
    pin = Pin(NEOPIXEL_PIN, Pin.OUT, value=0)
    strip = NeoPixel(pin, NUM_LEDS)
    strip.fill((0, 0, 0))
    strip.write()
    sleep_ms(50)
    return strip

def init_oled():
    i2c = I2C(0, scl=Pin(OLED_SCL_PIN), sda=Pin(OLED_SDA_PIN))
    oled = SH1106_I2C(OLED_W, OLED_H, i2c, addr=OLED_ADDR)
    oled.fill(0)
    oled.show()
    return i2c, oled

def init_audio():
    return I2S(0, sck=Pin(I2S_SCK_PIN), ws=Pin(I2S_WS_PIN), sd=Pin(I2S_SD_PIN),
               mode=I2S.TX, bits=16, format=I2S.MONO,
               rate=AUDIO_RATE, ibuf=AUDIO_BUF_SIZE)

def init_adc():
    adc = ADC(Pin(ADC_PIN))
    adc.atten(ADC.ATTN_11DB)
    return adc

def init_buttons():
    boot_btn = Pin(BOOT_BTN_PIN, Pin.IN)
    scan_btn = Pin(SCAN_BTN_PIN, Pin.IN)
    return boot_btn, scan_btn


# ══════════════════════════════════════════════════════════════════════════════
# SHARED UTILITIES
# ══════════════════════════════════════════════════════════════════════════════

def strip_clear(strip):
    strip.fill((0, 0, 0))
    strip.write()

def strip_all(strip, color):
    strip.fill(color)
    strip.write()

def oled_message(oled, line1, line2="", line3=""):
    oled.fill(0)
    oled.invert(False)
    if line1: oled.text(line1, max(0, (128 - len(line1) * 8) // 2), 16)
    if line2: oled.text(line2, max(0, (128 - len(line2) * 8) // 2), 30)
    if line3: oled.text(line3, max(0, (128 - len(line3) * 8) // 2), 44)
    oled.show()

def load_frames(path):
    frames = []
    with open(path, "rb") as f:
        while len(frames) < 30:
            data = f.read(FRAME_SIZE)
            if len(data) < FRAME_SIZE:
                break
            frames.append(bytearray(data))
    return frames

def open_wav(path):
    f = open(path, "rb")
    f.seek(0)
    header = f.read(44)
    if header[36:40] != b'data':
        while True:
            chunk = f.read(8)
            if not chunk or len(chunk) < 8:
                break
            if chunk[:4] == b'data':
                break
            size = chunk[4] | (chunk[5]<<8) | (chunk[6]<<16) | (chunk[7]<<24)
            f.seek(size, 1)
    return f

def play_wav_simple(path):
    """Play a WAV file with no animation — for caught/notcaught sounds."""
    audio = None
    wav   = None
    try:
        audio    = init_audio()
        mono_buf = bytearray(MONO_BUF_SIZE)
        wav      = open_wav(path)
        while True:
            num = wav.readinto(mono_buf)
            if num == 0:
                break
            if num < MONO_BUF_SIZE:
                for i in range(num, MONO_BUF_SIZE):
                    mono_buf[i] = 0
            audio.write(mono_buf)
    finally:
        if wav:   wav.close()
        if audio: audio.deinit()

def play_audio_with_animation(oled, frames, wav_path, draw_fn):
    audio = None
    wav   = None
    try:
        audio    = init_audio()
        mono_buf = bytearray(MONO_BUF_SIZE)
        wav      = open_wav(wav_path)
        frame_i  = 0
        loop_count = 0
        while True:
            num = wav.readinto(mono_buf)
            if num == 0:
                break
            if num < MONO_BUF_SIZE:
                for i in range(num, MONO_BUF_SIZE):
                    mono_buf[i] = 0
            audio.write(mono_buf)
            if loop_count % 6 == 0:
                draw_fn(oled, frames[frame_i % len(frames)])
                frame_i += 1
            loop_count += 1
    finally:
        if wav:   wav.close()
        if audio: audio.deinit()

def read_adc_average(adc):
    total = 0
    for _ in range(ADC_SAMPLES):
        total += adc.read()
        sleep_ms(25)
    return total // ADC_SAMPLES

def check_long_press(btn, duration_ms):
    if btn.value() == 0:
        t = ticks_ms()
        while btn.value() == 0:
            if ticks_diff(ticks_ms(), t) >= duration_ms:
                return True
            sleep_ms(50)
    return False

def wait_for_button_release(btn):
    while btn.value() == 0:
        sleep_ms(20)


# ══════════════════════════════════════════════════════════════════════════════
# BOOT / SCAN ANIMATIONS
# ══════════════════════════════════════════════════════════════════════════════

BOOT_COLORS = [
    (150, 120, 0),
    (0,   150, 0),
    (150, 0,   0),
] * 6

def boot_animation(oled, strip):
    oled_message(oled, "POKEDEX", "Booting...")
    strip_clear(strip)
    for i in range(NUM_LEDS):
        strip[i] = BOOT_COLORS[i]
        strip.write()
        sleep_ms(80)
    sleep_ms(600)
    for i in range(NUM_LEDS - 1, -1, -1):
        strip[i] = (0, 0, 0)
        strip.write()
        sleep_ms(40)
    strip_clear(strip)

def scan_animation(strip):
    strip_clear(strip)
    for i in range(NUM_LEDS):
        strip[i] = (0, 80, 0)
        strip.write()
        sleep_ms(50)


# ══════════════════════════════════════════════════════════════════════════════
# CATCHING MECHANIC
# ══════════════════════════════════════════════════════════════════════════════
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

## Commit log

2026-04-22 Create STL 3D print files
2026-04-22 Create stl
